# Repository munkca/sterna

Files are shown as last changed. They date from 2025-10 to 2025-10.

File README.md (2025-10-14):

# sterna
30-key hot-swap wireless keyboard based on the Tern.

This is my remodeled and personalized [Tern](https://github.com/rschenk/tern/)/[tern-ble](https://gitlab.com/gleb_sexy/tern-ble/) adapted to my personal preferences. I used this adaptation as a means to get familiar with Ergogen and kiCAD.

Differences from the Tern/Tern-ble:
- choc-spacing (17.5 x 16.5 mm)
- more splay and stagger
- wireless
- on/off switch
- reset button
- bottom case with acrylic keyplate

## Warning
This is an untested work in progress. I will let you know once I have built and tested this keyboard.

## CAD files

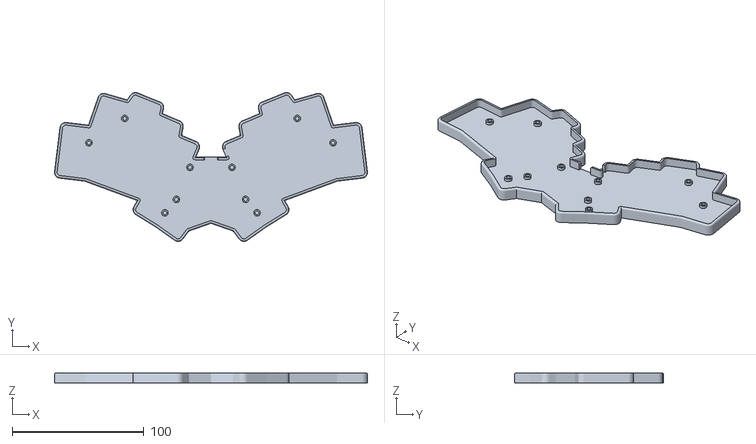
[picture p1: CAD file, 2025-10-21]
case/sterna-case-001.stl
237.3 x 112.8 x 7.80

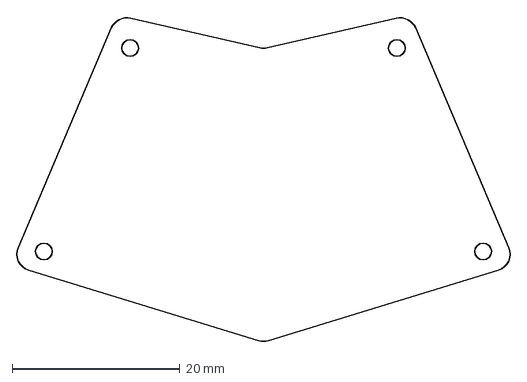
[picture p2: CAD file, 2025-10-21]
case/mcu_cover.dxf
59.0 x 38.8 mm

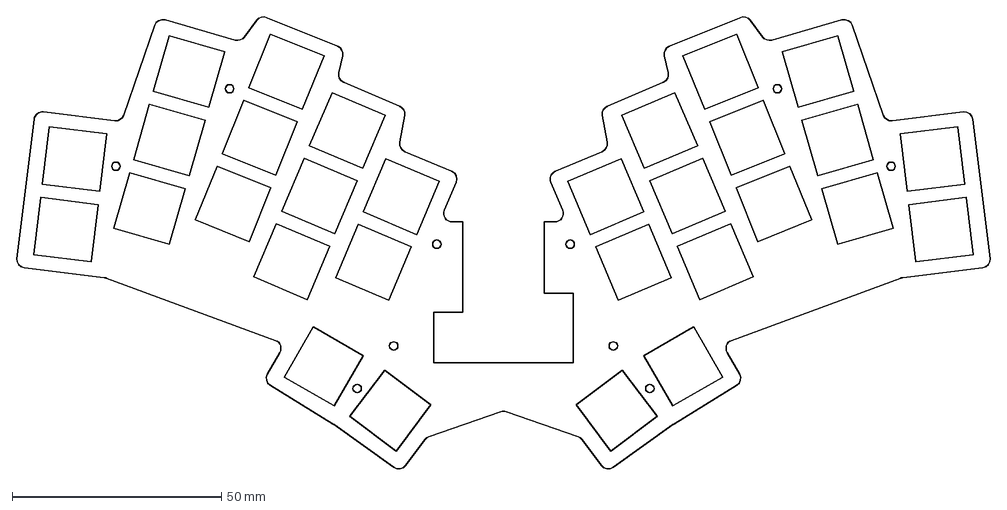
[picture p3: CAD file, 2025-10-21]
case/top_plate.dxf
232.5 x 108.3 mm

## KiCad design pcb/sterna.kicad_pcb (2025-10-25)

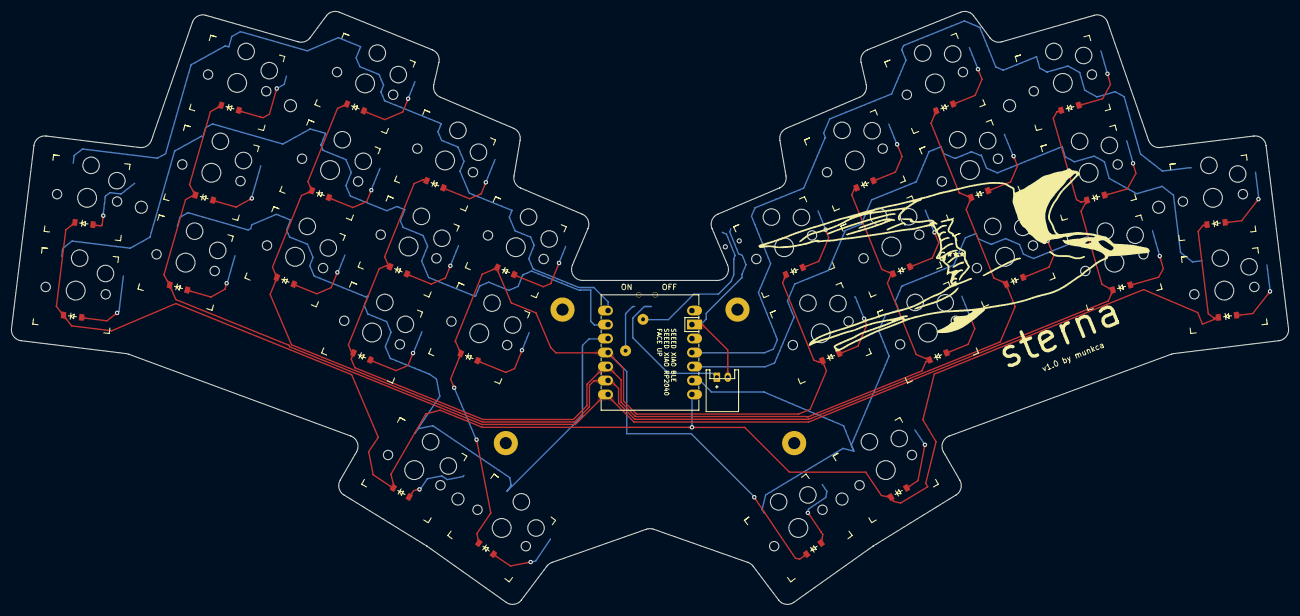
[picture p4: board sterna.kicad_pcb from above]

Board: 2 copper layers, 232.3 x 107.8 mm, 74 parts (1 on the bottom side), 45 nets.

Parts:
B1: Panasonic_EVQPUL_EVQPUC
D1, D2, D3, D4, D5, D6, D7, D8, D9, D10, D11, D12, D13, D14, D15, D16, D17, D18, D19, D20, D21, D22, D23, D24, D25, D26, D27, D28, D29, D30: ComboDiode
JST1: JST_PH_S2B-PH-K_02x2.00mm_Angled
MCU1: xiao-ble
PAD1, PAD2, PAD3, PAD4: MountingHole_2.2mm_M2_Pad
PAD5, PAD6, PAD7, PAD8, PAD9, PAD10: MountingHole_2.2mm_M2
S1, S2, S3, S4, S5, S6, S7, S8, S9, S10, S11, S12, S13, S14, S15, S16, S17, S18, S19, S20, S21, S22, S23, S24, S25, S26, S27, S28, S29, S30: Kailh_socket_PG1350
T1: SPDT_C128955

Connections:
BAT+: MCU1.19, T1.1
BAT_POS: JST1.1, T1.2
C0: D12.1, D13.1, D25.1, D26.1, D28.1, D30.1, MCU1.4
C1: D9.1, D10.1, D11.1, D22.1, D23.1, D24.1, MCU1.5
C2: D6.1, D7.1, D8.1, D19.1, D20.1, D21.1, MCU1.6
C3: D3.1, D4.1, D5.1, D16.1, D17.1, D18.1, MCU1.7
C4: D1.1, D2.1, D14.1, D15.1, D27.1, D29.1, MCU1.8
GND: B1.2, JST1.2, MCU1.13
R0: MCU1.1, S2.1, S5.1, S8.1, S11.1, S13.1
R1: MCU1.2, S1.1, S4.1, S7.1, S10.1, S12.1
R2: MCU1.3, S3.1, S6.1, S9.1, S27.1, S28.1
R3: MCU1.9, S16.1, S19.1, S22.1, S29.1, S30.1
R4: MCU1.10, S14.1, S17.1, S20.1, S23.1, S25.1
R5: MCU1.11, S15.1, S18.1, S21.1, S24.1, S26.1
RST: B1.1, MCU1.17
home_thumb: D27.2, S27.2
index_bottom: D9.2, S9.2
index_home: D10.2, S10.2
index_top: D11.2, S11.2
inner_home: D12.2, S12.2
inner_top: D13.2, S13.2
middle_bottom: D6.2, S6.2
middle_home: D7.2, S7.2
middle_top: D8.2, S8.2
mirror_home_thumb: D29.2, S29.2
mirror_index_bottom: D22.2, S22.2
mirror_index_home: D23.2, S23.2
mirror_index_top: D24.2, S24.2
mirror_inner_home: D25.2, S25.2
mirror_inner_top: D26.2, S26.2
mirror_middle_bottom: D19.2, S19.2
mirror_middle_home: D20.2, S20.2
mirror_middle_top: D21.2, S21.2
mirror_pinky_bottom: D14.2, S14.2
mirror_pinky_home: D15.2, S15.2
mirror_reachy_thumb: D30.2, S30.2
mirror_ring_bottom: D16.2, S16.2
mirror_ring_home: D17.2, S17.2
mirror_ring_top: D18.2, S18.2
pinky_bottom: D1.2, S1.2
pinky_home: D2.2, S2.2
reachy_thumb: D28.2, S28.2
ring_bottom: D3.2, S3.2
ring_home: D4.2, S4.2
ring_top: D5.2, S5.2

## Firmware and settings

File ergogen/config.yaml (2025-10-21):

meta:
  engine: 4.1.0
units:

  # Proxy Spacing Variables
  kx: cx
  ky: cy
  default_width: kx
  default_height: ky

  # Padding Variables
  px: kx + 2
  py: ky + 2
   # Keycap size
  capw: 17.5        # MBK keycaps
  caph: 16.5
   # Mirroring
  center_spread: 1.5capw # Distance between inner top keys
  master_angle: 22  # Degrees that the halves are angled (20)
  # Stagger
  ring_stagger: 9 #8
  middle_stagger: 7.5 #5.5
  index_stagger: -7.375 #5.375
  inner_stagger: -py/2
  # Splay
  ring_splay: 9     # Between pinky and ring (7)
  middle_splay: 6   # Between ring and middle(4)
  index_splay: 1

  # Thumb cluster
  thumb_shift_x: 0
  thumb_shift_y: -ky+7.5 #+5 originally
  thumb_splay: 7

  # Outlines
  edge_border: 2    # Border around PCB, outside the keycaps' perimeter
  outer_kx: capw + 2edge_border
  outer_ky: caph + 2edge_border
  xiao_cutout_x: 19.5
  xiao_cutout_y: 22.5
  mounting_hole_r: 1
  clearance_hole_r: 1.6
  cover_hole_margin: 3  # Inset from the edge
  casewall: 2 # thickness of case wall
  case_kx: outer_kx + 2casewall
  case_ky: outer_ky + 2casewall

  # bump the top-center of the mcu cover down to match the master angle
  cover_bump_top: -4
  cover_bump_home: -9 # ditto on bottom
  standoff_clearance_hole_r: 2.75

  # Components
  xiao_w: 17.5
  xiao_h: 21
  bat_plug_w: 7.6
  bat_plug_h: 5.9
  bat_w: 32   #401030
  bat_h: 12

  # Laser cutting
  kerf: 0.006 * 25.4 # Inches



 

points:
  zones:
    matrix:
      # Fix placement on KiCAD sheet
      anchor:
        shift: [108, -100]
      mirror: &mirror
        ref: matrix_inner_top
        distance: center_spread
        shift: [capw/2, caph/2]
      rotate: -master_angle
      key:
        padding: ky
        spread: kx
        tags: [key]

      columns:
        pinky:
          key:
            splay: ring_splay + middle_splay
          rows:
            bottom:
              row_net: R1
              column_net: C4
            home:
              row_net: R0
              column_net: C4
            top:
              skip: true
            bottom.mirror:
              row_net: R4
              column_net: C4
            home.mirror:
              row_net: R5
              column_net: C4

        ring:
          key:
            stagger: ring_stagger
            splay: -ring_splay
            origin: [-kx/2, -ky/2]
          rows:
            bottom:
              row_net: R2
              column_net: C3
            home:
              row_net: R1
              column_net: C3
            top:
             row_net: R0
             column_net: C3
            bottom.mirror:
              row_net: R3
              column_net: C3
            home.mirror:
              row_net: R4
              column_net: C3
            top.mirror:
             row_net: R5
             column_net: C3

        middle:
          key:
            stagger: middle_stagger
            splay: -middle_splay
            origin: [-kx/2, -ky/2]
          rows:
            bottom:
              row_net: R2
              column_net: C2
            home:
              row_net: R1
              column_net: C2
            top:
             row_net: R0
             column_net: C2
            bottom.mirror:
              row_net: R3
              column_net: C2
            home.mirror:
              row_net: R4
              column_net: C2
            top.mirror:
             row_net: R5
             column_net: C2

        index:
          key:
            stagger: index_stagger
            splay: -index_splay
            origin: [-kx/2, -ky/2]
          rows:
            bottom:
              row_net: R2
              column_net: C1
            home:
              row_net: R1
              column_net: C1
            top:
             row_net: R0
             column_net: C1
            bottom.mirror:
              row_net: R3
              column_net: C1
            home.mirror:
              row_net: R4
              column_net: C1
            top.mirror:
             row_net: R5
             column_net: C1

        inner:
          key:
            stagger: inner_stagger
          rows:
            bottom:
              skip: true
            home:
              row_net: R1
              column_net: C0
            top:
             row_net: R0
             column_net: C0
            home.mirror:
              row_net: R4
              column_net: C0
            top.mirror:
             row_net: R5
             column_net: C0

      rows:
        bottom:
        home:
        top:

  zones.thumbs:
      mirror: *mirror
      anchor:
        ref: matrix_inner_bottom
        shift: [thumb_shift_x, thumb_shift_y]
      key:
        padding: ky
        spread: kx
        tags: [key]

      columns:
        home:
          key:
            splay: -thumb_splay
            origin: [-kx/2, kx/2]
            row_net: R2
            column_net: C4
          key.mirror:
            row_net: R3
            column_net: C4
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

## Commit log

2025-10-18 Add M2 mounting hole footprint definition
2025-10-18 Add button_side_push footprint module
2025-10-18 Add MCU cover mounting hole footprint module
2025-10-18 Add case wall thickness and define case1 structure
2025-10-18 Refactor config.yaml for edge border and holes
    Updated edge border size and modified mounting hole definitions. Removed unused case definitions and adjusted keycap and switch hole references.
2025-10-26 Create build.yaml for board and shield setup
    Add build configuration for GitHub Actions matrix
